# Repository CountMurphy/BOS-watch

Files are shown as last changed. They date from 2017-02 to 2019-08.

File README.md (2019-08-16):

Brotherhood of Steel Watch
========================
Ad Victoriam!

Ad Victoriam brother!

The BOS watch is the second version of my GPS enabled wristwatches. Stripped of the non used features and annoyances of the [Pipman](https://random-hackery.net/post/pipman-gps-watch/) , the BOS watch contains all things a man traveling the wastes could want

[Official Page](https://random-hackery.net/post/bos-watch/)

Features
---------------
- GPS time syncing - get local time anywhere on earth at power up

- Tilt compensated compass (with LED directional indicators and exact heading information)

- Stop watch / countdown timer

- Speaker (Plays the fallout theme!)

- TV B-gone

- A Frickn' Laser!&trade;

- Low power usage

- USB charging

-  Gieger Counter sound emulator (planned at least)

- Retro look and feel using custom DIP switches (with 7 operating modes) and 1970's era calculator display bubble LEDs

Tech
---------
The BOS watch uses an arm processor and C (Huzzah! No more awful propeller spin code)

License
----------
[DBAD](https://github.com/philsturgeon/dbad/blob/master/LICENSE-en.md)

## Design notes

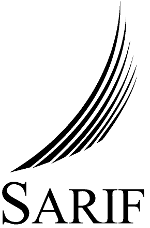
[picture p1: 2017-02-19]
images/sarif.bmp

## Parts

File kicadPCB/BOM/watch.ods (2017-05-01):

Part | Value | Device | Package | Description | BTM_NEG | BTM_POS | CPU | FLASHKB | MANUFACTURER_PART_NUMBER | MAXFREQUENCY | MF | MPN | OC_FARNELL | OC_NEWARK | PACKAGE | PINCOUNT | PROD_ID | SPICEMODEL | SPICEPREFIX | SPICETYPE | SRAMKB | STOREFRONT | TOP_NEG | TOP_POS | VALUE | VENDOR
12CR2 | 10K | RESISTOR0603 | 0603-RES | Resistor
C1 | 1uf | CAP0603 | 603 | Capacitor
C2 | 1uf | CAP0603 | 603 | Capacitor
C3 | 4.7uF | 0.1UF-25V(+80/-20%)(0603) | 0603-CAP | CAP-00810 |  |  |  |  |  |  |  |  |  |  |  |  | CAP-00810 |  |  |  |  |  |  |  | 0.1uF
C4 | 4.7uF | 0.1UF-25V(+80/-20%)(0603) | 0603-CAP | CAP-00810 |  |  |  |  |  |  |  |  |  |  |  |  | CAP-00810 |  |  |  |  |  |  |  | 0.1uF
C5 | .1uf | CAP0603 | 603 | Capacitor
C6 | .1uf | CAP0603 | 603 | Capacitor
C7 | .1uf | CAP0603 | 603 | Capacitor
C8 | .1uf | CAP0603 | 603 | Capacitor
C9 | .001uf | CAP0603 | 603 | Capacitor
COMPCAP | .1uf | CAP0603 | 603 | Capacitor
DISP1 | 7-SEGMENT-4DIGIT-COUNTER-HP-BUBBLE | 7-SEGMENT-4DIGIT-COUNTER-HP-BUBBLE | DIL12 |  |  |  |  |  |  |  |  |  |  |  |  |  |  |  |  |  |  | COM-12710
DISP2 | 7-SEGMENT-4DIGIT-COUNTER-HP-BUBBLE | 7-SEGMENT-4DIGIT-COUNTER-HP-BUBBLE | DIL12 |  |  |  |  |  |  |  |  |  |  |  |  |  |  |  |  |  |  | COM-12710
GPTX | 330 | RESISTOR0603 | 0603-RES | Resistor
I2CR1 | 10K | RESISTOR0603 | 0603-RES | Resistor
IC1 | ISL1209 | ISL1209 | MSOP10 | ISL1209
J2 | USB-MICROB | USB-MICROB | USB-MICROB | USB Connectors |  |  |  |  |  |  |  |  |  |  |  |  | CONN-09505
LASER | LD | LD | LD-FLUSH-WITH-JUMPER
LED-E |  | LED5MM | LED5MM | LED
LED-IR |  | LED5MM | LED5MM | LED
LED-N |  | LED5MM | LED5MM | LED
LED-S |  | LED5MM | LED5MM | LED
LED-W |  | LED5MM | LED5MM | LED
LED1 |  | LED_ESML0603 | LED_SML0603 | LED |  |  |  |  |  |  |  |  |  |  |  |  |  | NONE | D | diode
LIPO |  | JST_2MM_MALE | JST-2-SMD | Mates to single-cell LiPo batteries. | - | + | adafruit |  |  |  |  |  |  |  |  |  | CONN-11443 |  |  |  |  |  | - | +
Q1 | 32.768 KHz | CRYSTALTC26H | TC26H | CRYSTAL |  |  | adafruit |  |  |  |  |  | unknown | unknown
R1 | 2K | RESISTOR0603 | 0603-RES | Resistor
R2 | 470 | RESISTOR0603 | 0603-RES | Resistor
R3 | 680 | RESISTOR0603 | 0603-RES | Resistor
R4 | 680 | RESISTOR0603 | 0603-RES | Resistor
R5 | 680 | RESISTOR0603 | 0603-RES | Resistor
R6 | 680 | RESISTOR0603 | 0603-RES | Resistor
R7 | 680 | RESISTOR0603 | 0603-RES | Resistor
R8 | 680 | RESISTOR0603 | 0603-RES | Resistor
R9 | 680 | RESISTOR0603 | 0603-RES | Resistor
R10 | 680 | RESISTOR0603 | 0603-RES | Resistor
R11 | 220Ohm | RESISTOR0603 | 0603-RES | Resistor
R12 | 220Ohm | RESISTOR0603 | 0603-RES | Resistor
R13 | 220Ohm | RESISTOR0603 | 0603-RES | Resistor
R14 | 220Ohm | RESISTOR0603 | 0603-RES | Resistor
R15 | 220Ohm | RESISTOR0603 | 0603-RES | Resistor
R16 | 10 | RESISTOR0603 | 0603-RES | Resistor
R17 | 10K | RESISTOR0603 | 0603-RES | Resistor
R26 | 10K | RESISTOR0603 | 0603-RES | Resistor
R27 | 10K | RESISTOR0603 | 0603-RES | Resistor
R29 | 10K | RESISTOR0603 | 0603-RES | Resistor
R30 | 10K | RESISTOR0603 | 0603-RES | Resistor
S1 | EG1213 | EG1213 | EG1213 | E-Switch right-angle slide SPDT Part #EG1213
SP1 | SPEAKER/PS12 | SPEAKER/PS12 | PS12 | SPEAKER Source: BuerklinAdded PS12 (for part # PS1240 piezo) http://www.ladyada.net/library/pcb/eaglelibrary.html |  |  | adafruit
SWD_BREAKOUT | SWD_BREAKOUTS | SWD_BREAKOUTS | SWD
T1 | BC850 | BC850 | SOT23 | NPN TRANSISTOR
T2 |  | -PNP-SOT23-EBC | SOT23-EBC | PNP Transistror
U$1 | HMC6343A | HMC6343A | LCC36
U$2 | MCP73831 | MCP73831 | SOT23-5 | MCP73831 Miniature Single-Cell, Fully Integrated Li-Ion, Li-Polymer Charge Management Controllers
U$3 | DIPS | DIPS | DIPS
U$4 | 74HC595PW | 74HC595PW | 74HC595PW
U$5 | 74HC595PW | 74HC595PW | 74HC595PW
U$7 | DIPS | DIPS | DIPS
U$8 | DIPS | DIPS | DIPS
U$9 | DIPS | DIPS | DIPS
U1 |  | GPS_FGPMMOPA6H | FGPMMOPA6H | GPS Module - MTK MT3339 Chipset, -165dBm sensitivity, 22 channels, 10Hz, auto-select external antenna options
U2 | MKL27Z256VLH4 | MKL27Z256VLH4 | LQFP-64_10X10X1.6 |  |  |  | ARM Cortex-M0+ | 256 | mkl27z256vlh4 | 48 |  |  |  |  | LQFP | 64 |  |  |  |  | 32 |  |  |  |  | FREESCALE
 | http://www.digikey.com/short/3wrdnr

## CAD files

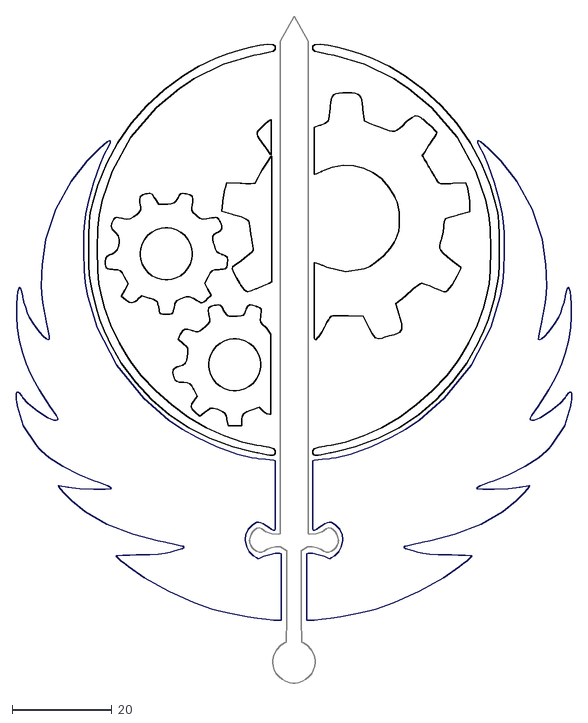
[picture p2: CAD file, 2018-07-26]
case/outfile.dxf
111.1 x 133.4

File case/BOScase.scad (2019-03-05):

include<knurledFinishLib.scad>
include<polyScrewThread.scad>

module board(){

    union(){
        linear_extrude(1.6){  
            difference(){
                square(size=[81.24,53.12]);
                translate([19.90,0]){
                    polygon(points=[[0,0],[43.22,0],[33.72,7.89],[10.20,7.89]]);
                }
            }
        };

        //GPS
        translate([63.05,23,1.6]){
            color([1,0,1]){
                cube([15.13,15.13,5]);}
        };
    };

    //LEDS
    translate([71.39,16.80,1.6]){
        color([1,1,1]){
            cylinder(h=8.1,r=2.5);
        }
    };
    translate([71.39,5.26,1.6]){
        color([1,1,1]){
            cylinder(h=8.1,r=2.5);
        }
    };
    translate([65.80,11.3,1.6]){
        color([1,1,1]){
            cylinder(h=8.1,r=2.5);
        }
    };
    translate([76.74,11.3,1.6]){
        color([1,1,1]){
            cylinder(h=8.1,r=2.5);
        }
    };

    //buzzer
    translate([22.21,38.15,1.6]){
        color([0,1,1]){
            cylinder(r=11.80/2,h=6.62);
        };
    };


    //laser
    translate([9.87,53.35,(6.42-1.6-(5.9/2))]){
        color([1,0,0]){
            rotate([90,90,0]) {
                cylinder(r=(5.9/2),h=10);
            };
        };
    };

    //usb
    rotate([90,0,90]){
        translate([45.21,4,75.24]){
            minkowski() {
                linear_extrude(5.56)
                    polygon([[-7.25/2,0], [7.25/2,0],
                            [7.25/2,-1], [5.25/2,-2.3],
                            [-5.25/2,-2.3], [-7.25/2,-1]]);
                cylinder(r=0.5, h=1);
            }    
        }
    }
    //screen
    translate([25.8,14.33,1.6]){
        color([1,0,0]){
            cube([30.90,8.43,5.25]);
        };
    };

    //toggles
    translate([11,17.32,1.6]){
        color([0,0,1]){
            union(){
                cube([9.5,4.95,7.52]);
                translate([(9.5/2),(4.95/2),7.52]){
                    cylinder(r=4.03/2,h=4.03);
                };
                translate([9.5/2,4.95/2,7.52+4.03]){
                    cylinder(h=9.95,r=2.7/2);
                }
            };
        };
    };

    translate([11,11.96,1.6]){
        color([0,0,1]){
            union(){
                cube([9.5,4.95,7.52]);
                translate([(9.5/2),(4.95/2),7.52]){
                    cylinder(r=4.03/2,h=4.03);
                };
                translate([9.5/2,4.95/2,7.52+4.03]){
                    cylinder(h=9.95,r=2.7/2);
                }
            };
        };
    };
    translate([11,6.35,1.6]){
        color([0,0,1]){
            union(){
                cube([9.5,4.95,7.52]);
                translate([(9.5/2),(4.95/2),7.52]){
                    cylinder(r=4.03/2,h=4.03);
                };
                translate([9.5/2,4.95/2,7.52+4.03]){
                    cylinder(h=9.95,r=2.7/2);
                }
            };
        };
    };
    translate([11,0.99,1.6]){
        color([0,0,1]){
            union(){
                cube([9.5,4.95,7.52]);
                translate([(9.5/2),(4.95/2),7.52]){
                    cylinder(r=4.03/2,h=4.03);
                };
                translate([9.5/2,4.95/2,7.52+4.03]){
                    cylinder(h=9.95,r=2.7/2);
                }
            };
        };
    };
    //power switch
    translate([64.23,48.92,1.6,]){
        union(){
            color([0,0,1]){
                cube([10.12,3.80,(6.86-1.6)]);
                translate([3.80,3.8,2.5])
                    cube([1.90,4.82,2.03]);
            }}
    }
    //bat
    translate([44.38,44.01,1.6]){
        color([0,1,0]){
            cube([6.25,7.93,(7.32-1.6)]);
        }
    }
    //rtc?
    translate([57.58,38.57,1.6]){
        // cylinder(h=13.75-1.6,r=2.94/2);
    }
    //SWD pins
    translate([14.5,44.33,1.6]){
        cube([2.35,7.78,7.13]);
    }
    //ir
    translate([23,53.10-5.44,1.6]){
        cube([4.5,2.43,5.13]);
    }
}

module boardBaseOnly(){
    union(){
        linear_extrude(5.6){  //got to exagerate to make hole in bottom
            translate([-1.5,-1.5,0]){
                square(size=[82.74,55.62]);
                translate([19.90,0]){
                    // polygon(points=[[0,0],[43.22,0],[33.72,7.89],[10.20,7.89]]);
                }
            }
        };
        //laser
        translate([8.15,53.35+40,(6.42-1.6-(5.9/2))]){
            color([1,0,0]){
                rotate([90,90,0]) {
                    cylinder(r=(7.4/2),h=50);
                };
            };
        };
        //power switch
        translate([64.23,48.92,1.6,]){
            union(){
                color([0,0,1]){
                    cube([10.12,3.80,(6.86-1.6)]);
                    translate([3.80,3.8,2.5])
                        cube([1.90,4.82,2.03]);
                }}
        };

        //usb
        rotate([90,0,90]){
            translate([45.21,4,75.24]){
                minkowski() {
                    linear_extrude(15.56)
                        polygon([[-7.25/2,0], [7.25/2,0],
                                [7.25/2,-1], [5.25/2,-2.3],
                                [-5.25/2,-2.3], [-7.25/2,-1]]);
                    cylinder(r=0.5, h=1);
                }    
            }
        }
    };
}    

module boardBaseTop(){
    union(){
        linear_extrude(1.6){  
            difference(){
                square(size=[81.24,53.12]);
                translate([19.90,0]){
                    polygon(points=[[0,0],[43.22,0],[33.72,7.89],[10.20,7.89]]);
                }
            }
        };

        //GPS
        translate([63.05-5.5,19,1.6]){
            color([1,0,1]){
                cube([20.63,25.63,5]);}
        };
    };

    //LEDS
    translate([71,11,1]){
        //led group hole
        color([0,1,0]){
            cylinder(r=9,h=10);
        }
    }
    translate([71.39,16.80,1.6]){
        color([1,1,1]){
            rotate([0,0,90]){
                cylinder(h=12,r=3,$fn=3);
            }
        }
    };
    translate([71.39,5.26,1.6]){
        color([1,1,1]){
            rotate([0,0,30]){
                cylinder(h=12,r=3,$fn=3);
            }
        }
    };
    translate([65.80,11.3,1.6]){
        color([1,1,1]){
            rotate([0,0,180]){
                cylinder(h=12,r=3,$fn=3);
            }
        }
    };
    translate([76.74,11.3,1.6]){
        color([1,1,1]){
            cylinder(h=12,r=3,$fn=3);
        }
    };

    //buzzer
    translate([20.76,38.15,1.6]){
        color([0,1,1]){
            cylinder(r=14/2,h=6.62);
        };
    };


    //laser
    translate([9.15,53.35+40,(6.42-1.6-(5.9/2))]){
        color([1,0,0]){
            rotate([90,90,0]) {
                cylinder(r=(7.4/2),h=60);
            };
        };
    };

    //usb
    rotate([90,0,90]){
        translate([45.21,4,75.24]){
            minkowski() {
#linear_extrude(15.56)
                polygon([[-10.25/2,0], [10.25/2,0],
                        [10.25/2,-1], [8.25/2,-5.3],
                        [-8.25/2,-5.3], [-10.25/2,-1]]);
                cylinder(r=.5, h=1);
            }    
        }
    }
    //screen
    translate([24.8,14.33,1.6]){
        color([1,0,0]){
            cube([31.90,8.43,10.25]);
        };
    };

    //toggles
    translate([11,.5,1.6]){
        cube([10,22,7.54]);
    }


    //compass
    translate([1.5,23.5,2.5]){
        cube([13.5,32,2.5]);
    }
    //power switch
    translate([62,48.92,1.6,]){
        union(){
            color([0,0,1]){
#cube([11.62,15.80,(6.86-1.6)]);
                translate([3.80,3.8,2.5])
                    cube([1.90,4.82,2.03]);
            }}
    }
    //bat
    translate([42.84-5,44.01,1.6]){
        color([0,1,0]){
            cube([16,8.93,(7.32-1.6)]);
        }
    }
    //rtc?
    translate([27.58,26.57,3]){
#cube([47.8,18.63,5]);
    }
    //SWD pins
    translate([12.5,44.33,1.6]){
        cube([4.5,9.78,7.73]);
    }
    translate([14.5,41.33,3]){
#cube([2.5,5,2]);
    }
    //ir
    translate([22.5,53.10-5.44,1.6]){
        cube([5.5,15.43,8.13]);
    }
}

module pins(){
    color([0,1,0]){
        //Create Pins
        union(){
            translate([25,10,-2]){
                rotate([0,90,0]){
                    translate([4,0,0]){
                        //pin
                        cylinder(r=4.82/2,h=30.39);
                    }
                }
                translate([-1.5,0,-7]){
                    rotate([0,0,45]){
                        cylinder(9,2,7,$fn=4);
                    }
                }
                translate([32,0,-7]){
                    rotate([0,0,45]){
                        cylinder(9,2,7,$fn=4);
                    }
                }
            }
        }
    }
}

module bottom(){
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

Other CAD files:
case/knurledFinishLib.scad
case/polyScrewThread.scad
case/polyScrewThread_r1.scad

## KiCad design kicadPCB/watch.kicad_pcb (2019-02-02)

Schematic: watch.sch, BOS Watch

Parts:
12CR2: 10K; SPARKFUN-RESISTORS_0603-RES
C1, C2: 1uf; SPARKFUN_0603
C3, C4: 4.7uF; SPARKFUN-CAPACITORS_0603-CAP
C5, C6, C7, C8: .1uf; SPARKFUN_0603
C9: .001uf; SPARKFUN_0603
COMPCAP46: .1uf; SPARKFUN_0603
D1, D2, D3, D4, D5: LED; LED_D5.0mm
DISP1, DISP2: 7-SEGMENT-4DIGIT-COUNTER-HP-BUBBLE; SPARKFUN-DISPLAYS_DIL12
GPTX46: 330; SPARKFUN-RESISTORS_0603-RES
I2CR1: 10K; SPARKFUN-RESISTORS_0603-RES
IC1: ISL1209; ADAFRUIT_MSOP10
J1: USB_OTG; USB_Micro-B
LASER46: LD; PHOTONICS_LD-FLUSH-WITH-JUMPER
LED1: EAGLE-LTSPICE_LED_SML0603
LIPO46: SPARKFUN-CONNECTORS_JST-2-SMD
LS1: Speaker; ADAFRUIT_PS12
M1: BOS_LIBS_SWD_BREAKOUTS; BOS_LIBS_SWD2
Q1: Q_PNP_CEB; SOT-23
R1: 2K; SPARKFUN-RESISTORS_0603-RES
R2: 470; SPARKFUN-RESISTORS_0603-RES
R3, R4, R5, R6, R7, R8, R9, R10: 330; SPARKFUN-RESISTORS_0603-RES
R11, R12, R13, R14, R15: 220Ohm; SPARKFUN-RESISTORS_0603-RES
R16: 10; SPARKFUN-RESISTORS_0603-RES
R17, R26, R27, R29, R30: 10K; SPARKFUN-RESISTORS_0603-RES
R18: 330k; R_0603_1608Metric
S11: EG1213; ADAFRUIT_EG1213
T1: BC850; TRANSISTOR_SOT23
U1: ADAFRUIT_FGPMMOPA6H
U2: MKL27Z256VLH4; FREESCALE_LQFP-64_10X10X1.6
U$1: HMC6343A; SPARKFUN_LCC36
U$2: MCP73831; GEEKAMMO_SOT23-5
U$3, U$7, U$8, U$9: DIPS; BOS_LIBS_DIPS
U$4, U$5: 74HC595PW; BOS_LIBS_74HC595PW
Y1: Crystal; CRYSTAL_TC26H

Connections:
/N$1: U$1.22 (CS), U$1.35 (CSC)
/N$2: U2.15 (VREFL), U2.16 (VSSA)
/N$3: C4.2, LIPO46.2 (+), S11.2, U$2.3 (VBAT)
/N$4: C3.2, J1.1 (VBUS), LED1.A, U$2.4 (VDD)
/N$5: LED1.C, R2.1
/N$6: C2.1, C9.1, Q1.3 (C), U1.P$1 (VCC)
/N$7: R2.2, U$2.1 (STAT)
/N$8: R1.1, U$2.5 (PROG)
/N$9: DISP1.1 (D1), R3.1
/N$10: DISP1.10 (D2), R5.1
/N$11: DISP1.12 (A), DISP2.12 (A), U$4.Q0
/N$12: DISP1.4 (D3), R6.1
/N$13: DISP1.6 (D4), R4.1
/N$14: DISP2.1 (D1), R7.1
/N$15: DISP2.10 (D2), R8.1
/N$16: DISP1.7 (G), DISP2.7 (G), U$4.Q6
/N$17: DISP1.5 (DP), DISP2.5 (DP), U$4.Q7
/N$18: R9.2, U$5.Q6
/N$19: DISP1.9 (F), DISP2.9 (F), U$4.Q5
/N$20: DISP2.4 (D3), R9.1
/N$21: DISP1.8 (D), DISP2.8 (D), U$4.Q3
/N$22: R8.2, U$5.Q5
/N$23: R7.2, U$5.Q4
/N$24: R4.2, U$5.Q3
/N$25: R6.2, U$5.Q2
/N$26: DISP2.6 (D4), R10.1
/N$27: R3.2, U$5.Q0
/N$28: U$4.Q7S, U$5.DS
/N$29: R10.2, U$5.Q7
/N$30: GPTX46.1, U1.P$9 (TX)
/N$31: R5.2, U$5.Q1
/N$35: D4.1 (K), R12.2
/N$36: D5.1 (K), R11.2
/N$37: D2.1 (K), R14.2
/N$38: D3.1 (K), R13.2
/N$39: D1.1 (K), R15.2
/N$40: LASER46.C, R16.1
/N$41: R16.2, T1.3 (C)
/N$43: IC1.1 (XTALI), Y1.2
/N$44: IC1.2 (XTALO), Y1.1
/N$47: DISP1.2 (E), DISP2.2 (E), U$4.Q4
/N$50: DISP1.11 (B), DISP2.11 (B), U$4.Q1
/N$51: DISP1.3 (C), DISP2.3 (C), U$4.Q2
/PTA0: M1.2 (SWD_CLK), U2.22 (PTA0)
/PTA1: R26.2, U2.23 (PTA1), U$7.VCC (V)
/PTA3: M1.1 (SWD_DIO), U2.25 (PTA3)
/PTA4: R27.2, U2.26 (PTA4), U$3.VCC (V)
/PTA5: U2.27 (PTA5)
/PTA12: U2.28 (PTA12)
/PTA13: U2.29 (PTA13)
/PTA18: U2.32 (PTA18)
/PTA19: U2.33 (PTA19)
/PTB1: U2.36 (PTB1)
/PTB2: U2.37 (PTB2)
/PTB3: U2.38 (PTB3)
/PTB16: U2.39 (PTB16), U$4.DS
/PTB17: U2.40 (PTB17)
/PTB18: U2.41 (PTB18), U$4.OE, U$5.OE
/PTB19: U2.42 (PTB19)
/PTC0: U2.43 (PTC0)
/PTC2: U2.45 (PTC2)
/PTC3: U2.46 (PTC3/LLWU_P7), U$4.SHCP, U$5.SHCP
/PTC4: R18.2, U2.49 (PTC4/LLWU_P8)
/PTC7: U2.52 (PTC7)
/PTC8: 12CR2.1, IC1.8 (SCL), U2.53 (PTC8), U$1.32 (SCL)
/PTC9: I2CR1.1, IC1.7 (SDA), U2.54 (PTC9), U$1.36 (SDA)
/PTC10: U1.P$5 (3D-FIX), U2.55 (PTC10)
/PTC11: U2.56 (PTC11)
/PTD1: D2.2 (A), U2.58 (PTD1)
/PTD2: GPTX46.2, U2.59 (PTD2)
/PTD3: D5.2 (A), U2.60 (PTD3)
/PTD4: U2.61 (PTD4/LLWU_P14), U$4.STCP, U$5.STCP
/PTD5: D4.2 (A), U2.62 (PTD5)
/PTE0: D3.2 (A), U2.1 (PTE0)
/PTE1: R17.1, T1.1 (B), U2.2 (PTE1)
/PTE20: D1.2 (A), U2.9 (PTE20)
/PTE24: R29.1, U2.20 (PTE24), U$9.VCC (V)
/PTE25: R30.2, U2.21 (PTE25), U$8.VCC (V)
/PTE30: LS1.1, U2.18 (PTE30)
GND: C1.2, C2.2, C3.1, C4.1, C5.1, C6.1, C7.1, C8.1, C9.2, COMPCAP46.2, IC1.4 (GND), J1.5 (GND), LIPO46.1 (-), LS1.2, M1.3 (GND), R1.2, R11.1, R12.1, R13.1, R14.1, R15.1, R17.2, T1.2 (E), U1.P$3 (GND), U1.P$8 (GND), U1.P$12 (GND), U1.P$19 (GND), U2.4 (VSS_2), U2.31 (VSS_3), U2.47 (VSS), U$1.25 (GND), U$1.29 (GND), U$2.2 (VSS), U$3.GND, U$4.GND, U$5.GND, U$7.GND, U$8.GND, U$9.GND
unnamed: Q1.1 (B), R18.1

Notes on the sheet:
place near MCU VCC

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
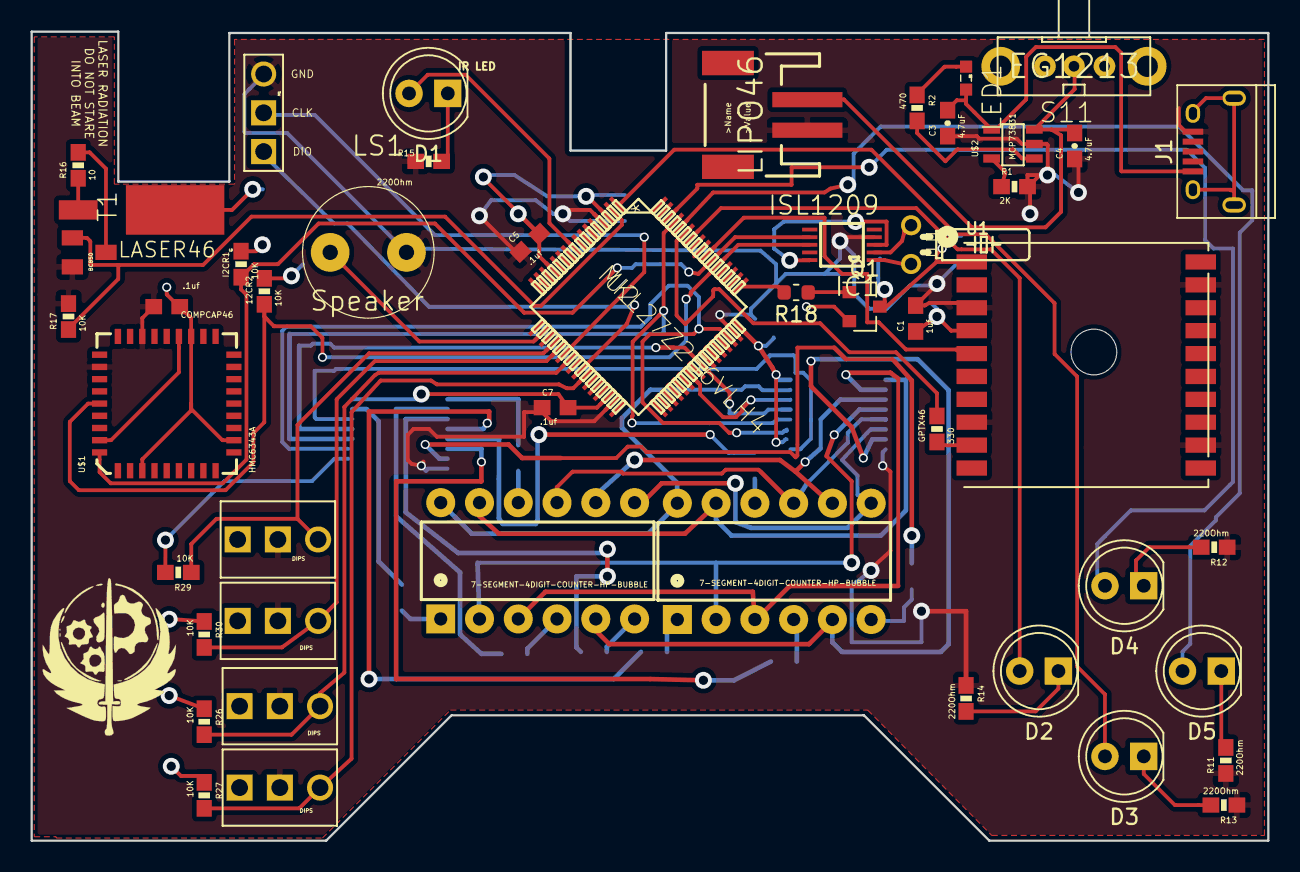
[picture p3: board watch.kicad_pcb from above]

Board: 2 copper layers, 81.0 x 53.0 mm, 63 parts (0 on the bottom side), 68 nets.

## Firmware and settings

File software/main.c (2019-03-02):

// Standard C Included Files
#include <stdio.h>
#include <string.h>
// SDK Included Files
#include "fsl_os_abstraction.h"
#include "fsl_smc_hal.h"


#include "pins.h"
#include "screen.h"
#include "buzzer.h"
#include "rtc.h"
#include "gps.h"
#include "switch.h"
#include "compass.h"
#include "pewpew.h"


/* Configuration for enter VLPR mode. Core clock = 4MHz. */
static const clock_manager_user_config_t g_defaultClockConfigVlpr = {   
    .mcgliteConfig =
    {    
        .mcglite_mode       = kMcgliteModeLirc8M,   // Work in LIRC_8M mode.
        .irclkEnable        = true,  // MCGIRCLK enable.
        .irclkEnableInStop  = false, // MCGIRCLK disable in STOP mode.
        .ircs               = kMcgliteLircSel8M, // Select LIRC_8M.
        .fcrdiv             = kMcgliteLircDivBy1,    // FCRDIV is 0.
        .lircDiv2           = kMcgliteLircDivBy1,    // LIRC_DIV2 is 0.
        .hircEnableInNotHircMode         = false, // HIRC disable.
    },
    .simConfig =
    {    
        .er32kSrc  = kClockEr32kSrcOsc0,   // ERCLK32K selection, use OSC.
        .outdiv1   = 1U, // divide by 2, core clock = 8 MHz / 2
        .outdiv4   = 3U, // divide by 4, bus clock = 4 MHz / 4
    },
    .oscerConfig =
    {   
        .enable       = false, // OSCERCLK disable.
        .enableInStop = false, // OSCERCLK disable in STOP mode.
    }
};

/* Configuration for enter RUN mode. Core clock = 48MHz. */
static const clock_manager_user_config_t g_defaultClockConfigRun = {
    .mcgliteConfig =
    {   
        .mcglite_mode        = kMcgliteModeHirc48M,   // Work in HIRC mode.
        .irclkEnable        = false, // MCGIRCLK disable.
        .irclkEnableInStop  = false, // MCGIRCLK disable in STOP mode.
        .ircs               = kMcgliteLircSel2M, // Select LIRC_2M.
        .fcrdiv             = kMcgliteLircDivBy1,    // FCRDIV is 0.
        .lircDiv2           = kMcgliteLircDivBy1,    // LIRC_DIV2 is 0.
        .hircEnableInNotHircMode         = true,  // HIRC disable.
    },
    .simConfig =
    {   
        .er32kSrc  = kClockEr32kSrcOsc0,  // ERCLK32K selection, use OSC.
        .outdiv1   = 0U,
        .outdiv4   = 1U,
    },
    .oscerConfig =
    {
        .enable       = false, // OSCERCLK disable.
        .enableInStop = false, // OSCERCLK disable in STOP mode.
    }
};

// /* Idle the CPU in Very Low Power Wait (VLPW) */
// /* This should be the lowest power mode where the PIT still functions. */
// static const smc_power_mode_config_t g_idlePowerMode = {
//     .powerModeName = kPowerModeVlpw,
// };

static bool isLowPower=false;

static void AdjustPowerMode(bool islow)
{
    if(islow)
    {
        CLOCK_SYS_SetConfiguration(&g_defaultClockConfigVlpr);
    isLowPower=true;
    }
    else
    {
        CLOCK_SYS_SetConfiguration(&g_defaultClockConfigRun);
    isLowPower=false;
    }

}

static void RunClock(void)
{
    uint8_t second;
    uint8_t minute;
    uint8_t hour;

    ReadHourMinute(&minute,&hour);
    second = ReadSecond();

    while(!InterruptTriggered())
    {
        switch(GetSubMode())
        {
        case 0:
                second = ReadSecond();
                if(second==0x00)
                {
                    ReadHourMinute(&minute,&hour);
                }
            printTime(hour,minute,second);
            break;
        case 1:
            printDate();
            break;
        case 2:
            PrintDOW();
            break;
        }
    }
}

static void RunBuzzer()
{
    bool dots[5]={false,false,false,false,false};
    while(!InterruptTriggered())
    {
        switch(GetSubMode())
        {
        case 0:
            multiplex("audio",dots,5);
            break;
        case 1:
            PlayTheme();
            break;
        case 2:
            Gieger();
            break;
        case 3:
            TakeOnMe();
            break;
        }
    }
}

static void toggleDirectionLight(uint16_t heading)
{
    if((heading>=340 && heading <=360)|| (heading >=0 && heading<=20))
    {
        //North
        GPIO_DRV_WritePinOutput(LED_North.pinName,1);
        GPIO_DRV_WritePinOutput(LED_East.pinName,0);
        GPIO_DRV_WritePinOutput(LED_West.pinName,0);
        GPIO_DRV_WritePinOutput(LED_South.pinName,0);
    }else if(heading >20 && heading <=40)
    {
        //North East
        GPIO_DRV_WritePinOutput(LED_North.pinName,1);
        GPIO_DRV_WritePinOutput(LED_East.pinName,0);
        GPIO_DRV_WritePinOutput(LED_West.pinName,1);
        GPIO_DRV_WritePinOutput(LED_South.pinName,0);
    }else if(heading >40 && heading <=120)
    {
        //East
        GPIO_DRV_WritePinOutput(LED_North.pinName,0);
        GPIO_DRV_WritePinOutput(LED_East.pinName,0);
        GPIO_DRV_WritePinOutput(LED_West.pinName,1);
        GPIO_DRV_WritePinOutput(LED_South.pinName,0);
    }else if(heading >120 && heading <=150)
    {
        //South East
        GPIO_DRV_WritePinOutput(LED_North.pinName,0);
        GPIO_DRV_WritePinOutput(LED_East.pinName,0);
        GPIO_DRV_WritePinOutput(LED_West.pinName,1);
        GPIO_DRV_WritePinOutput(LED_South.pinName,1);
    }else if(heading >150 && heading <=220)
    {
        //South
        GPIO_DRV_WritePinOutput(LED_North.pinName,0);
        GPIO_DRV_WritePinOutput(LED_East.pinName,0);
        GPIO_DRV_WritePinOutput(LED_West.pinName,0);
        GPIO_DRV_WritePinOutput(LED_South.pinName,1);
    }else if(heading >200 && heading <=230)
    {
        //South West
        GPIO_DRV_WritePinOutput(LED_North.pinName,0);
        GPIO_DRV_WritePinOutput(LED_East.pinName,1);
        GPIO_DRV_WritePinOutput(LED_West.pinName,0);
        GPIO_DRV_WritePinOutput(LED_South.pinName,1);
    }else if(heading > 230 && heading <=300)
    {
        //West
        GPIO_DRV_WritePinOutput(LED_North.pinName,0);
        GPIO_DRV_WritePinOutput(LED_East.pinName,1);
        GPIO_DRV_WritePinOutput(LED_West.pinName,0);
        GPIO_DRV_WritePinOutput(LED_South.pinName,0);
    }else if(heading >300 && heading <340)
    {
        //North West
        GPIO_DRV_WritePinOutput(LED_North.pinName,1);
        GPIO_DRV_WritePinOutput(LED_East.pinName,1);
        GPIO_DRV_WritePinOutput(LED_West.pinName,0);
        GPIO_DRV_WritePinOutput(LED_South.pinName,0);
    }
}

static void RunCompass()
{
    Resume();
    OSA_TimeDelay(1);
    while(!InterruptTriggered())
    {
        uint16_t heading = GetHeading();
        bool dots[4]={false,false,true,false};
        bool dotsUnder100[4]={false,true,false,false};
        bool dotsUnder10[4]={true,false,false,false};
        bool wordDots[8]={false,false,false,false,false,false,false,false};
        char charHead[4];
        switch(GetSubMode())
        {
            case 0:
                multiplex("compass",wordDots,8);
                break;
            case 1:
                sprintf (charHead, "%u", heading);
                if(heading/10 <10)
                {
                    multiplex(charHead,dotsUnder10,2);
                }else if(heading/10 <100)
                {
                    multiplex(charHead,dotsUnder100,3);
                }else{
                    multiplex(charHead,dots,4);
                }
                break;
            case 2:
                sprintf (charHead, "%u", heading);
                if(heading/10 <10)
                {
                    multiplex(charHead,dotsUnder10,2);
                }else if(heading/10 <100)
                {
                    multiplex(charHead,dotsUnder100,3);
                }else{
                    multiplex(charHead,dots,4);
                }

                heading=heading/10;
                toggleDirectionLight(heading);
                break;
        }
    }
    StndBy();
    GPIO_DRV_WritePinOutput(LED_North.pinName,0);
    GPIO_DRV_WritePinOutput(LED_East.pinName,0);
    GPIO_DRV_WritePinOutput(LED_West.pinName,0);
    GPIO_DRV_WritePinOutput(LED_South.pinName,0);
}

static void PrintRawGPS()
{
    bool latDots[11]={false,false,false,false,false,false,false,false,false,false,false};
    char lat[9];
    char lon[10];
    char N_S;
    char E_W;

#if !DEBUG
    GPSPower(true);
    WaitOnSatFix();
    powerDisplay(true);
    PlayAlarm();
#endif
    GetCurrentLocation(lat,&N_S,lon,&E_W);
    GPSPower(false);
    while(!InterruptTriggered())
    {

        char fullLat[11];
        strcpy(fullLat,lat);
        fullLat[9]=N_S;
        Scroll(fullLat,latDots,9);
        char fullLon[11];
        strcpy(fullLon,lon);
        fullLon[10]=E_W;
        Scroll(fullLon,latDots,10);
    }
}

static void PrintGoogleGPS()
{
    bool latDots[11]={false,false,false,false,false,false,false,false,false,false,false};
    char lat[9];
    char lon[10];
    double gLat;
    double gLon;
    char N_S;
    char E_W;

#if !DEBUG
    GPSPower(true);
    WaitOnSatFix();
    powerDisplay(true);
    PlayAlarm();
#endif
    GetCurrentLocation(lat,&N_S,lon,&E_W);
    GetGoogleReadyLocation(lat,N_S,lon,E_W,&gLat,&gLon);
    char chargLat[9];
    char chargLon[10];
    int ret =snprintf(chargLat, 9, "%f", 30.356145);
    if(ret<0)
    {
        ret=2;
    }
    while(!InterruptTriggered())
    {
        Scroll(chargLat,latDots,9);
        snprintf(chargLon, 10, "%f", gLon);
        Scroll(chargLon,latDots,10);
    }
}

static void RunGPS()
{
    bool dots[3]={false,false,false};
    bool wasLowPower=isLowPower;

    while(!InterruptTriggered())
    {
        switch(GetSubMode())
        {
        case 0:
            multiplex("gps",dots,3);
            break;
        case 1:
            if(wasLowPower)
            {
                //UART only runs in high power mode
                AdjustPowerMode(false);
            }
            PrintRawGPS();
            break;
        case 2:
            //print google ready
            if(wasLowPower)
            {
                AdjustPowerMode(false);
            }
            PrintGoogleGPS();
            break;
        }
    }
    if(wasLowPower)
    {
        AdjustPowerMode(true);
    }
}

static void RunPewPew()
{
    bool dots[5]={false,false,false,false,false};
    while(!InterruptTriggered())
    {
        switch(GetSubMode())
        {
            case 0:
                multiplex("Armed",dots,5);
                FirnMahLaser(false);
                break;
            case 1:
                FirnMahLaser(true);
                break;
        }
    }
    FirnMahLaser(false);
}



static void RunStandBy()
{
    bool dots[6]={false,false,false,false,false,false};
    while(!InterruptTriggered())
    {
        switch(GetSubMode())
        {
            case 0: 
                multiplex("Power",dots,5);
                break;
            case 1: 
                for(int i=0;i<50;i++)
                {
                    multiplex("Stndby",dots,6);
                }
                powerDisplay(false);
                while(!InterruptTriggered())
                {
                    //idle
                }
                break;
            case 2:
                if(GetMode()==1)
                {
                    multiplex("Low",dots,3);
                    AdjustPowerMode(true);
                }else if(GetMode()==0)
                {
                    multiplex("High",dots,4);
                    AdjustPowerMode(false);
                }
                break;
        }
    }
}


static void CreateStopWatchString(char countedTime[],int8_t hour,int8_t minute,int8_t second)
{
    char minChar[2],hourChar[2],secChar[2];
    sprintf (hourChar, "%u", hour);
    sprintf (minChar, "%u", minute);
    sprintf (secChar, "%u", second);
    countedTime[0]=hourChar[0];
    countedTime[1]=hourChar[1];
    countedTime[2]='\0';
    countedTime[3]=minChar[0];
    countedTime[4]=minChar[1];
    countedTime[5]='\0';
    countedTime[6]=secChar[0];
    countedTime[7]=secChar[1];
}

static void SetCountDownTime(int8_t *hour,int8_t *minute,int8_t *second)
{
    *hour=0;
    *minute=0;
    *second=0;
    uint8_t mode=GetMode();
    char digToPrint[2];
    bool dots[2]={false,false};
    //Set hour
    for(int i=0;i<3;i++)
    {
        uint16_t timeDelay=0;
        while(mode==2)
        {
            mode=GetMode();
        }

        while(mode!=2)
        {
            mode=GetMode();
            switch(i)
            {
            case 0:
                digToPrint[0] = (*hour/10) + 48;
                digToPrint[1] = (*hour%10) +48;
                multiplex(digToPrint,dots,2);
                break;
            case 1:
                digToPrint[0]=(*minute/10) + 48;
                digToPrint[1]=(*minute%10) + 48;
                multiplex(digToPrint,dots,2);
                break;
            case 2:
                digToPrint[0]=(*second/10) + 48;
                digToPrint[1]=(*second%10) + 48;
                multiplex(digToPrint,dots,2);
                break;
            }
            if(mode==1 && timeDelay>=25)
            {
                timeDelay=0;
                switch(i)
                {
                case 0:
                    *hour+=1;
                    if(*hour==10)
                    {
                        *hour =0;
                    }
                    break;
                case 1:
                    *minute+=1;
                    if(*minute>59)
                    {
                        *minute=0;
                    }
                    break;
                case 2:
                    *second+=1;
                    if(*second>59)
                    {
                        *second=0;
                    }
                    break;
                }


            }
            timeDelay+=1;
        }
    }
}



static void RunStopWatch()
{
    int8_t minute=0;
    int8_t hour=0;
    int8_t second=0;
    int8_t milisecond=0;
    bool fuckingDots[8]={false,false,false,false,false,false,false,false};//for those grepping for swear words. You're welcome
    char countedTime[8];
    while(!InterruptTriggered())
    {
        
        switch(GetSubMode())
        {
        case 0:
            //stopwatch

            CreateStopWatchString(countedTime,hour,minute,second);
            //multiplex has a milisecond delay already
            multiplex(countedTime,fuckingDots,8);
            if(GetMode()==1)
            {
                milisecond++;
                if(milisecond==60)
                {
                    milisecond=0;
                    second++;
                    if(second==60)
                    {
                        second=0;
                        minute++;
                    }
                }
            }else if(GetMode()>1)
            {
                hour=minute=second=0;
            }
            break;
        case 1:
            //countdown
            milisecond=59;
            SetCountDownTime(&hour,&minute,&second);
            //If you're reading this, you've been in a coma for almost 20 years now. We're trying a new technique. We don't know where this message will end up in your dream, but we hope it works. Please wake up, we miss you.
            while(!InterruptTriggered())
            {
                CreateStopWatchString(countedTime,hour,minute,second);
                multiplex(countedTime,fuckingDots,8);
                milisecond--;
                if(second==0 && minute==0 && hour==0)
                {
                    while(!InterruptTriggered())
                    {
                        PlayAlarm();
                    }
                }else if(milisecond<0)
                {
                    milisecond=59;
                    second--;
                    if(second<0)
                    {
                        minute--;
                        second=59;
                        if(minute<0)
                        {
                            minute=59;
                            hour--;
                        }
                    }
                }
            }
            break;
        }
    }
}



int main (void)
{
    // Initialize
    hardware_init();
    OSA_Init();

    ScreenInit();
    SwitchInit();
    laserInit();
    CompassInit();
    GPSInit();
    //lights init
    GPIO_DRV_OutputPinInit(&LED_North);
    GPIO_DRV_OutputPinInit(&LED_South);
    GPIO_DRV_OutputPinInit(&LED_West);
    GPIO_DRV_OutputPinInit(&LED_East);
    
    //prompt for dst
    bool dst=false;
    while(GetFirstRun())
    {
        bool dots[8]={false,false,false,false,false,false,false,false};
        if(GetMode()==1 || GetMode()==3)
        {
            multiplex("is\0dst\0y",dots,8);
            dst=true;
        }else{
            multiplex("is\0dst\0n",dots,8);
            dst=false;
        }
    }

#if !DEBUG
    //turn on gps
    GPSPower(true);
#endif


    WaitOnSatFix();
    uint8_t minute;
    uint8_t second;
    uint8_t hour;
    uint8_t month;
    uint8_t day;
    uint8_t year;
    uint32_t lon;
    uint8_t dow;
    char direction;
    ParseNMEA(&minute,&hour,&second,&day,&month,&year,&lon,&direction);
    GPSPower(false);

    //set clocks
    int8_t offset=GetLocalTimeZoneOffset(lon,direction);

    if(dst==true)
    {
        offset+=1;
    }

    RTC_init();
    adjustDate(&day,&month,&year,offset,hour);
    hour = AdjustUTCHour(hour,offset);
    dow=dayofweek((2000+year),month,day);
    setRtc(hour,minute,second,month,day,year,dow);

    PlayTheme();

    //check for low power mode request
    if(GetMode()==2 || GetMode()==3)
    {
        //spin it down, turn off display
        AdjustPowerMode(true);
        powerDisplay(false);
        isLowPower=true;
        while(!InterruptTriggered())
        {
            //idle
        }
    }else{
        powerDisplay(true);
    }


    for(;;)
    {
        while(!InterruptTriggered())
        {
            uint8_t mode=GetMainMode();
            switch(mode)
            {
            case 0:
            {
                RunClock();
                break;
            }
            case 1:
            {
                RunCompass();
                break;
            }
            case 2:
            {
                RunPewPew();
                break;
            }
            case 3:
            {
                RunGPS();
                break;
            }
            case 4:
            {
                RunBuzzer();
                break;
            }
            case 5:
            {
                RunStopWatch();
                break;
            }
            case 6:
            {
                RunStandBy();
                break;
            }
            }
        }
    }
    

    return 0;
}

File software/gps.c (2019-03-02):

#include <stdint.h>
#include<stdio.h>
#include<math.h>
#include "fsl_gpio_driver.h"
#include "fsl_uart_driver.h"

#include "gps.h"
#include "pins.h"
#include "screen.h"
#include "switch.h"

static const gpio_output_pin_user_config_t GPSEnable={
    .pinName=GPIO_MAKE_PIN(GPIOC_IDX,4),
    .config.outputLogic=1
};

uart_state_t g_uartState;

static const gpio_input_pin_user_config_t SatFix={
    .pinName=GPIO_MAKE_PIN(GPIOC_IDX,10)
};

uart_user_config_t g_uartConfig= {
    .baudRate = 9600u,
    .parityMode = kUartParityDisabled,
    .stopBitCount = kUartOneStopBit,
    .bitCountPerChar = kUart8BitsPerChar,
};



void GPSInit()
{
    GPIO_DRV_OutputPinInit(&GPSEnable);
    GPIO_DRV_InputPinInit(&SatFix);
    UART_DRV_Init(2u, &g_uartState, &g_uartConfig);
}


void GPSPower(bool power)
{
    GPIO_DRV_WritePinOutput(GPSEnable.pinName,power?0:1);
}

uint8_t ReadChar()
{
    uint8_t rxChar;
    UART_DRV_ReceiveDataBlocking(2u, &rxChar, 1u,1000u);
    return rxChar;
}

void ParseNMEA(uint8_t *minutes,uint8_t *hours,uint8_t *seconds,uint8_t *day,uint8_t *month,uint8_t *year,uint32_t *lon,char *direction)
{
#if DEBUG
    char GPRMC[100] = "$GPRMC,193811.000,A,3000.0000,N,09000.0000,W,0.60,60.68,210418,,,A*4B\r\n";
    char GPGGA[100] = "$GPGGA,015833.000,3000.0000,N,09000.0000,W,1,04,3.21,171.0,M,-22.6,M,,*5B\r\n";
#else
    uint8_t NMEACount = 100;
    char GPRMC[NMEACount];
    char GPGGA[NMEACount];
    GetGPGGA(NMEACount,GPGGA);
    GetGPRMC(NMEACount,GPRMC);
#endif

    char hourChar[2];
    hourChar[0]=GPGGA[7];
    hourChar[1]=GPGGA[8];
    int temp;
    sscanf(hourChar, "%d", &temp);
    *hours=(uint8_t)temp;

    char minChar[2];
    minChar[0]=GPGGA[9];
    minChar[1]=GPGGA[10];
    sscanf(minChar, "%d", &temp);
    *minutes=(uint8_t)temp;

    char secChar[2];
    secChar[0]=GPGGA[11];
    secChar[1]=GPGGA[12];
    sscanf(secChar, "%d", &temp);
    *seconds=(uint8_t)temp;

    uint8_t startingParsePoint = 0;
    uint8_t commaHit = 0;

    for(int i=0;i<100;i++)
    {
        if(GPRMC[i]==',')
        {
            commaHit++;
        }
        if(commaHit==9)
        {
            startingParsePoint=i;
            break;
        }
        if(GPRMC[i]=='\r')
        {
            //something went horridly wrong
            break;
        }
    }

    char dayChar[2];
    dayChar[0]=GPRMC[startingParsePoint+1];
    dayChar[1]=GPRMC[startingParsePoint+2];
    sscanf(dayChar, "%d", &temp);
    *day=(uint8_t)temp;

    char monChar[2];
    monChar[0]=GPRMC[startingParsePoint+3];
    monChar[1]=GPRMC[startingParsePoint+4];
    sscanf(monChar, "%d", &temp);
    *month=(uint8_t)temp;

    char yearChar[2];
    yearChar[0]=GPRMC[startingParsePoint+5];
    yearChar[1]=GPRMC[startingParsePoint+6];
    sscanf(yearChar, "%d", &temp);
    *year=(uint8_t)temp;

    char lonChar[5];
    lonChar[0]=GPRMC[32];
    lonChar[1]=GPRMC[33];
    lonChar[2]=GPRMC[34];
    lonChar[3]=GPRMC[35];
    lonChar[4]=GPRMC[36];
    sscanf(lonChar, "%d", &temp);
    *lon=(uint32_t)temp;

    *direction=GPRMC[43];
}

void GetGPRMC(uint8_t NMEACount, char *GPRMC)
{
    bool parse=true;
    while(parse)
    {
        if(ReadChar()=='$')
        {
            GPRMC[0]='$';
            for(int i=1;i<NMEACount;i++)
            {
                //Verify string read
                if(i==6)
                {
                    if(GPRMC[4]!='M' || GPRMC[5]!='C')
                        break;
                }
                GPRMC[i]=ReadChar();
                if(GPRMC[i]=='\n')
                {
                    parse=false;
                    break;
                }
            }
        }
    }
}


void GetGPGGA(uint8_t NMEACount, char *GPGGA)
{
    bool parse=true;
    while(parse)
    {
        if(ReadChar()=='$')
        {
            GPGGA[0]='$';
            for(int i=1;i<NMEACount;i++)
            {
                //Verify string read
                if(i==6)
                {
                    if(GPGGA[4]!='G' || GPGGA[5]!='A')
                        break;
                }
                GPGGA[i]=ReadChar();
                if(GPGGA[i]=='\n')
                {
                    parse=false;
                    break;
                }
            }
        }
    }
}

void WaitOnSatFix()
{
    //set all segments to '8'
    uint8_t gpsWait[2]={0x00,0xFF};
    rawWriteToScreen(gpsWait);
    bool lastValue=GPIO_DRV_ReadPinInput(SatFix.pinName);
    OSA_TimeDelay(500);
    int count=0;
    while(!InterruptTriggered())
    {
        bool currentValue=GPIO_DRV_ReadPinInput(SatFix.pinName);
        if(currentValue==lastValue)
        {
            count++;
        }
        else{
            count=0;
        }
        //Sat Fix detection
#if DEBUG
        count=8;
#endif
        if(count==8)
        {
            return;
        }else{
            lastValue=currentValue;
        }

        if (currentValue)
        {
            powerDisplay(true);
        }else{
            powerDisplay(false);
        }
        OSA_TimeDelay(250);

    }
}



void GetCurrentLocation(char *lat, char *N_S,char*lon, char *E_W)
{
#if DEBUG
    char GPRMC[100] = "$GPRMC,193811.000,A,3000.0000,N,09000.0000,W,0.60,60.68,210418,,,A*4B\r\n";
#else
    char GPRMC[100];
    GetGPRMC(100,GPRMC);
#endif
    lon[0]=GPRMC[32];
    lon[1]=GPRMC[33];
    lon[2]=GPRMC[34];
    lon[3]=GPRMC[35];
    lon[4]=GPRMC[36];
    lon[5]=GPRMC[37];
    lon[6]=GPRMC[38];
    lon[7]=GPRMC[39];
    lon[8]=GPRMC[40];
    lon[9]=GPRMC[41];
    *E_W= GPRMC[43];

    lat[0]=GPRMC[20];
    lat[1]=GPRMC[21];
    lat[2]=GPRMC[22];
    lat[3]=GPRMC[23];
    lat[4]=GPRMC[24];
    lat[5]=GPRMC[25];
    lat[6]=GPRMC[26];
    lat[7]=GPRMC[27];
    lat[8]=GPRMC[28];
    *N_S=GPRMC[30];
}

void GetGoogleReadyLocation(char *lat,char N_S,char *lon, char E_W, double *gLat,double *gLon)
{

    //dumb ass work around as sscanf wont work with a float...
    int latWhole;
    int latDecimal;
    char latDecChar[4]={lat[5],lat[6],lat[7],lat[8]};
    sscanf(lat,"%d",&latWhole);
    sscanf(latDecChar,"%d",&latDecimal);

    int lonWhole;
    int lonDecimal;
    char lonDecChar[4]={lon[6],lon[7],lon[8],lon[9]};
    sscanf(lon,"%d",&lonWhole);
    sscanf(lonDecChar,"%d",&lonDecimal);

    *gLat=CoordConvert(latWhole,latDecimal);
    *gLon=CoordConvert(lonWhole,lonDecimal);

    if(N_S=='S')
    {
        *gLat*=-1;
    }
    if(E_W=='W')
    {
        *gLon*=-1;
    }
}

double CoordConvert(int coordWhole,int coordDecimal)
{
    double coorF=coordWhole+((float)coordDecimal*.0001);
    int firstDigits=(int)coorF/100;
    return firstDigits+((coorF-((double)firstDigits*100))/60);
}
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

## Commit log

2016-04-26 base layout
    [watch.sch]
2016-04-26 made less messy, added libs
    [watch.sch]
2016-04-26 wired more components
    [watch.sch]
2016-04-30 added swd breakouts
    [watch.sch]
2016-04-30 added charging unit
    [watch.sch]
2016-05-01 added labels
    [watch.sch]
2016-05-01 added pull up resistors
    [watch.sch]
2016-05-20 added shift regs to board
    [watch.sch]
2016-05-21 wired shift regs
    [watch.sch]
2016-05-21 wired registers to board
    [watch.sch]
2016-05-21 finished first run of shift registers
    [watch.sch]
2016-05-21 added compass leds
    [watch.sch]
2016-05-21 added IR led.
    [watch.sch]
2016-05-21 moved 5 way switch wiring
    [watch.sch]
2016-05-22 added laser diode for lulz
    [watch.sch]
2016-05-22 fixed gps fett
    [watch.sch]
2016-05-22 cleaned up gps, added label for gps cap
    [watch.sch]
2016-05-22 added vback cap
    [watch.sch]
2016-05-22 fixed gps cap
    [watch.sch]
2016-05-22 added mcu caps
    [watch.sch]
2016-05-22 added RTC crystal
    [watch.sch]
2016-05-23 I think the SR clocks are now wired correctly?
    [watch.sch]
2016-05-24 Moved Resistors from digit pins to segment pins and moved README image location to private server
    [watch.sch]
2016-05-25 added control switch resistors
    [watch.sch]
2016-07-08 reduced the amount of display resistors by more than half
    [watch.sch]
2016-07-08 placed brd resistors
    [watch.brd]
2016-07-09 added polygons
    [watch.brd]
2016-07-09 top row hooked up
    [watch.brd]
2016-07-09 wired most of the led display. TODO: wire SR together. God help me
    [watch.brd]
2016-07-10 fixed vcc layer
    [watch.brd]
2016-07-10 wired more of the SR
    [watch.brd]
2016-07-19 wired all SR but one pin
    [watch.brd, watch.sch]
2016-07-22 w00t! wired all SR
    [watch.brd]
2016-07-22 cleaned up crap
    [watch.brd]
2016-07-22 wired more resistors and traces
    [watch.brd]
2016-08-27 wired charging circuit
    [watch.brd]
2016-08-27 moved clock, rewired gps
    [watch.brd, watch.sch]
2016-08-27 rewired gps
    [watch.brd, watch.sch]
2016-08-27 laser wired
    [watch.brd]
2016-08-27 refactored charging circuit and add caps to it
    [watch.brd]
2016-08-28 wired compass LEDs. good god this thing is a mess
    [watch.brd]
2016-08-28 removed airwires, added decoupling caps
    [watch.brd, watch.sch]
2016-09-03 wired swd
    [watch.brd]
2016-09-03 fixed some fuck ups
    [watch.brd]
2016-09-03 moar refactoring
    [watch.brd]
2016-09-05 fixed more wiring issues. started i2c
    [watch.brd]
2016-09-05 fixed mroe air wires
    [watch.brd]
2016-09-15 wired decoupling caps
    [watch.brd]
2016-09-15 moved IR for smaller form factor
    [watch.brd]
2016-09-18 all but one decoup cap done
    [watch.brd]
2016-09-18 finished last decoupling cap
    [watch.brd]
2016-09-27 added gps tx resistor
    [watch.brd, watch.sch]
2016-09-27 altered values on gps caps
    [watch.brd, watch.sch]
2016-09-27 finished adding gps caps per https://cdn-shop.adafruit.com/datasheets/GlobalTop-FGPMMOPA6H-Datasheet-V0A.pdf page 26
    [watch.brd, watch.sch]
2016-10-18 added dip switches. need to check spaces for compass.
    [watch.brd, watch.sch]
2016-10-18 fixed last air wire
    [watch.brd]
2016-10-23 moved compass further from switches
    [watch.brd]
2016-10-23 started drc
    [watch.brd]
2016-10-23 more drc work
    [watch.brd]
2016-10-26 more drc, discovered cockup with trace overlap
    [watch.brd]
2016-10-26 overlaps fixed, reintroduced airwires
    [watch.brd]
2016-11-02 fixed air wires
    [watch.brd]
2016-11-18 final changes for drc
    [watch.brd]
2016-11-19 added brand logo to rear (giggity)
    [watch.brd]
2016-11-26 Board reshaped
    [watch.brd]
2017-01-13 moved usb
    [watch.brd]
2017-01-24 removed drill hole replaced with battery wire notch
    [watch.brd]
2017-01-24 fixed bad dip package
    [watch.brd, watch.sch]
2017-02-19 converted to kicad
    Eagle changed its licensing in a super dickish way. Done with that
    [watch.brd, watch.kicad_pcb, watch.sch]
2017-02-20 added laser warning text
    [watch.kicad_pcb]
2017-02-28 added clearer labels
    [watch.kicad_pcb]
2017-05-01 added BOM because KIcad BOM is terribad
    [watch.ods]
2017-05-10 added i2c thing
2017-05-27 got i2c working
2017-06-06 minor improvments
    [watch.sch]
2017-06-06 fixed spi1
    [watch.kicad_pcb, watch.sch]
2017-06-06 fixed resistor vals
    [watch.sch]
2017-06-06 fixed uart gps
    [watch.kicad_pcb, watch.sch]
2017-06-07 moved OE to a timer pin to control display brightness
    [watch.kicad_pcb, watch.sch]
2017-06-07 removed large retarded vias to better enable trace navigation
    [watch.kicad_pcb]
2017-06-07 wired storage clock together for SR
    [watch.kicad_pcb, watch.sch]
2017-06-08 fixed laser label
    [watch.kicad_pcb]
2017-06-09 fixed compass orientation
    [watch.kicad_pcb]
2017-06-09 fixed clock crystal
    [watch.kicad_pcb]
2017-12-25 lower case g
2018-01-17 added through hole usb
    [watch.kicad_pcb, watch.sch]
2018-01-17 fixed bad reset on SRs
    [watch.kicad_pcb, watch.sch]
2018-01-18 reversed IR LED
    [watch.kicad_pcb]
2018-01-18 fixed pnp
    [watch.kicad_pcb, watch.sch]
2018-01-21 fixed Laser npn, fixed laser and led south from bridge
    [watch.kicad_pcb, watch.sch]
2018-01-22 fixed labels
    [watch.kicad_pcb]
2018-02-13 added buzzer files I forgot to include (oops)
    [buzzer.c]
2018-05-02 Added switch menu system
2018-05-02 can now interrupt song
2018-05-12 Added Count down timer
2018-05-14 refactored code. issue #5
    [main.c, screen.c]
2018-05-14 added laser code, but laser will not fire. Hardware issue
    [main.c, pins.c]
2018-05-20 added case
    [BOScase.scad]
2018-05-20 mocked board
    [BOScase.scad]
2018-05-23 Created Botton of case
    [BOScase.scad]
2018-05-31 fixed debug gps bug
    [main.c]
2018-07-25 compass directional LEDs fixed
    [main.c]
2018-07-26 added pwr options, but going to HIGH from anything destroys the buzzer
    [main.c]
2018-07-26 Completed Case Work
    [BOScase.scad, knurledFinishLib.scad, outfile.dxf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]
2018-08-04 fixed date parse bug
    [gps.c]
2018-08-04 gps case adjust for second build
    [BOScase.scad]
2018-08-07 shorted led cover
    [BOScase.scad]
2018-08-09 fixed compass power bleed
    [compass.c, main.c]
2018-09-25 Fixed date parsing, again
    [gps.c]
2018-10-26 fixed countdown display over 10
    [main.c]
2018-11-16 refactored maths
    [BOScase.scad]
2019-01-23 tweaked battery depth in case
    [BOScase.scad]
2019-01-24 added low power mode request option on boot
2019-01-24 fixed power drain on standby.
    [main.c]
2019-01-26 fixed compass heading precision
    [main.c]
2019-01-27 fixed easily breakable screw
    [BOScase.scad]
2019-02-02 removed low power flicker
2019-02-02 added pnp resistor
    [watch.kicad_pcb, watch.sch]
2019-03-02 Fixed GPS non display bug
    [gps.c, main.c]
2019-03-05 added case nub to prevent opening
    [BOScase.scad]
